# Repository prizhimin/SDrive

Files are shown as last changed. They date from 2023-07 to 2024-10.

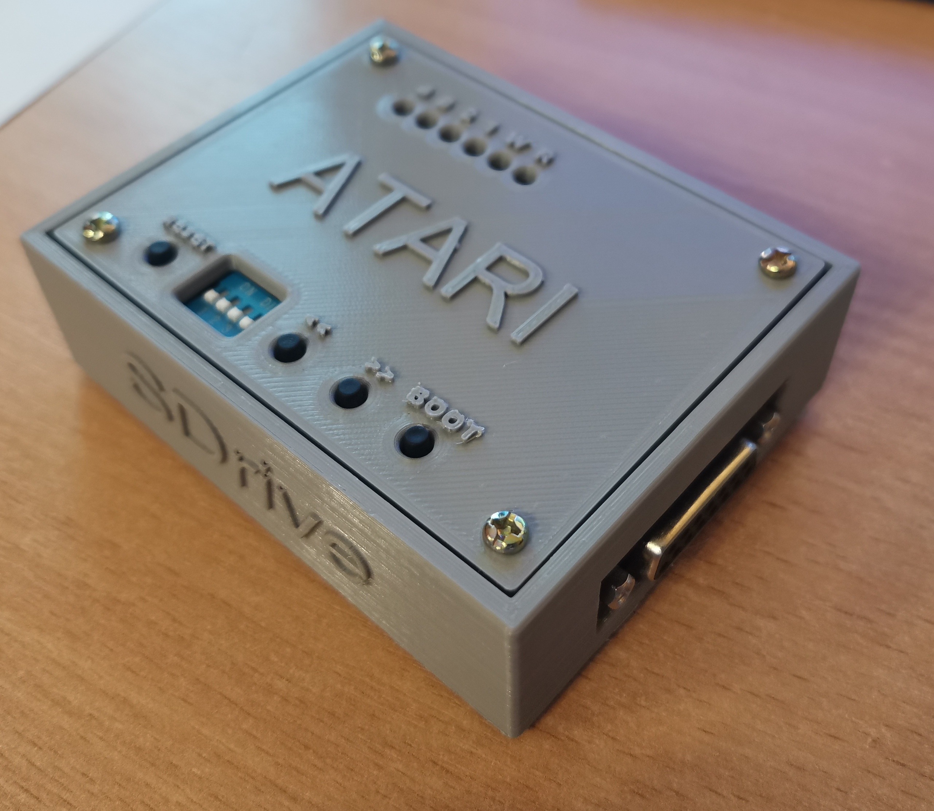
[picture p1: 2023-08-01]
Image 1.jpg

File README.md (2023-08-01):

# SDrive
Информация для создания эмулятора дисковода SDrive для 8-битных компьютеров Atari

Проверена работоспособность на Atari 65XE и Atari 130XL

Версия для микроконтроллера ATmega328P - поддержка карт SDHC и файловой системы FAT32

Оригинальный проект https://github.com/kbr-net/sdrive-ng

------------------------------------------------------------------------

Information for creating an SDrive Drive Emulator for Atari 8-bit computers

Tested performance on Atari 65XE and Atari 130XL

ATmega328P microcontroller version - support for SDHC cards and FAT32 file system

Original project https://github.com/kbr-net/sdrive-ng

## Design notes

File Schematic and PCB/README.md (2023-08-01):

Исходные файлы схемы и печатной платы в формате Diptrace 4

Source of Schematic and PCB in Diptrace 4 format

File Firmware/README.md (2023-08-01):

# SDrive Firmware and Soft

hex и eep - файлы прошивки

sdrive.atr - записать в корень SD-карты

Прошивка:
- во время прошивки все dip-переключатели должны быть внизу (разомкнуты), SD-карта не вставлена, питание 5 вольт подаётся
- прошивать в 2 захода: сначала flash (.hex) и фьюзы, потом eeprom (.eep)

Программатор USBasp с Aliexpress

Программируем при помощи avrdude https://github.com/avrdudes/avrdude

Команда для прошивки фьзов: 
avrdude.exe -p m328p -U lfuse:w:0xfe:m -U hfuse:w:0xd8:m efuse:w:0xfc:m -c usbasp

---------------------------------------------------------------

hex and eep firmware files

sdrive.atr - write to the root of the SD card

Firmware:

- during the firmware, all dip switches must be at the bottom (open), the SD card is not inserted, 5 volts of power is supplied

- to flash in 2 passes: first flash (.hex) and fuses, then eeprom (.eep)

The USBasp programmer with Aliexpress is programmed using avrdude https://github.com/avrdudes/avrdude

The command to burn fuzes: avrdude.exe -p m328p -U lfuse:w:0xfe:m -U hfuse:w:0xd8:m efuse:w:0xfc:m -c usbasp

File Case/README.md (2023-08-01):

# Case for SDrive

Корпус (верх и них) в формате SolidWorks и STL

Top and Bootom in SOLIDWORKS and STL formats

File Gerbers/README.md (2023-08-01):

Готовые герберы печатной платы для заказа на заводе

Ready-made gerbers for ordering PCB at the factory

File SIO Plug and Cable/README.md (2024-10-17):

3D-модель для SIO-коннектора

Взято отсюда https://github.com/schlae/atari-sio

Совместимо с контактами Molex 08-50-0106

Возможно подойдут контакты от разъёма PHU (PHU-6 (DS1072-6F)

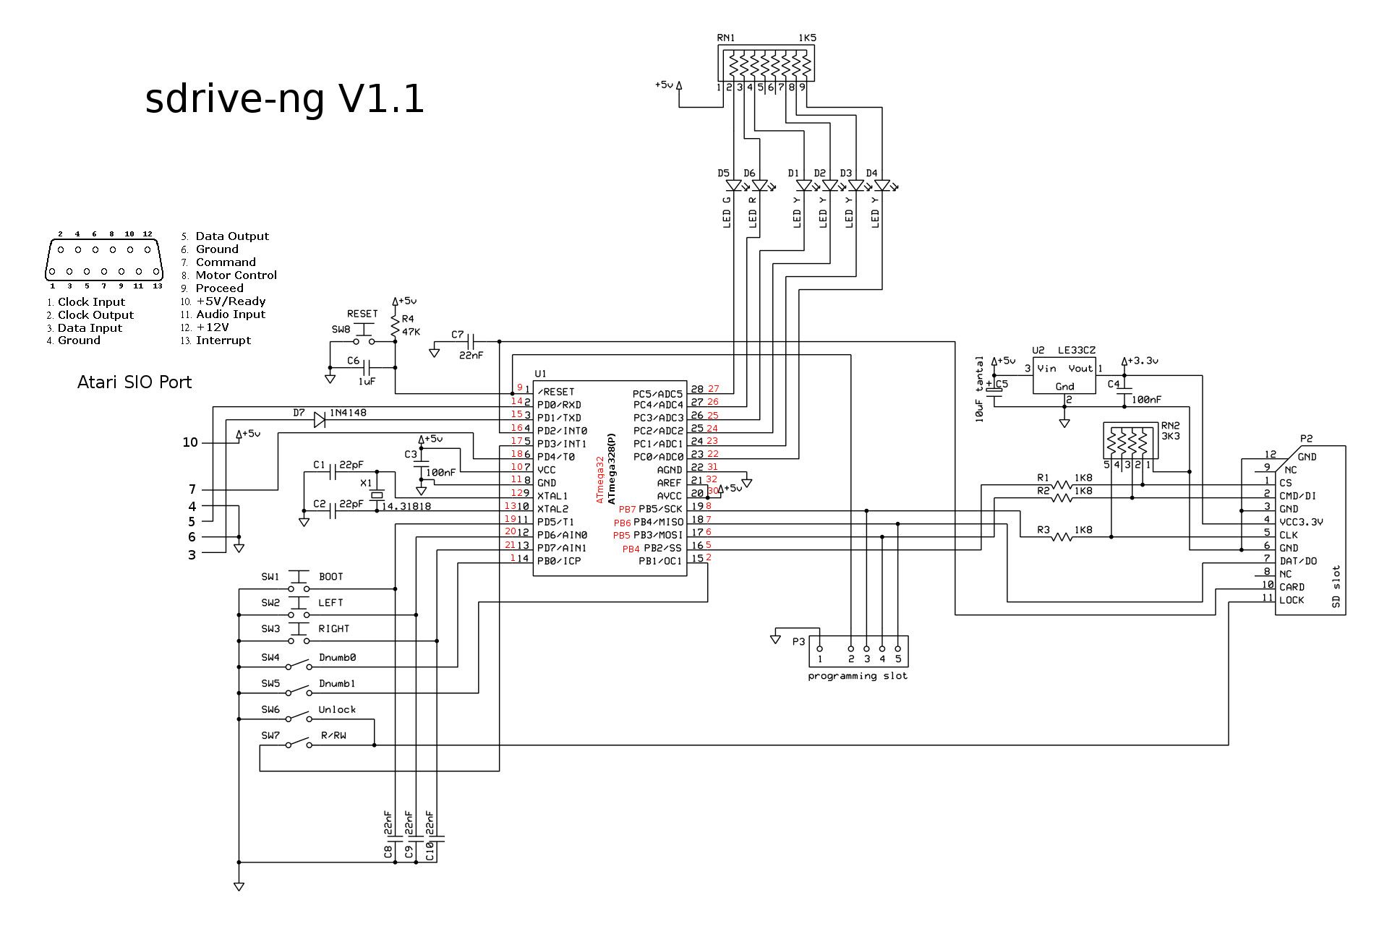
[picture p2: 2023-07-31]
Schematic and PCB/schema-sdrive-ng-v1.1.jpg

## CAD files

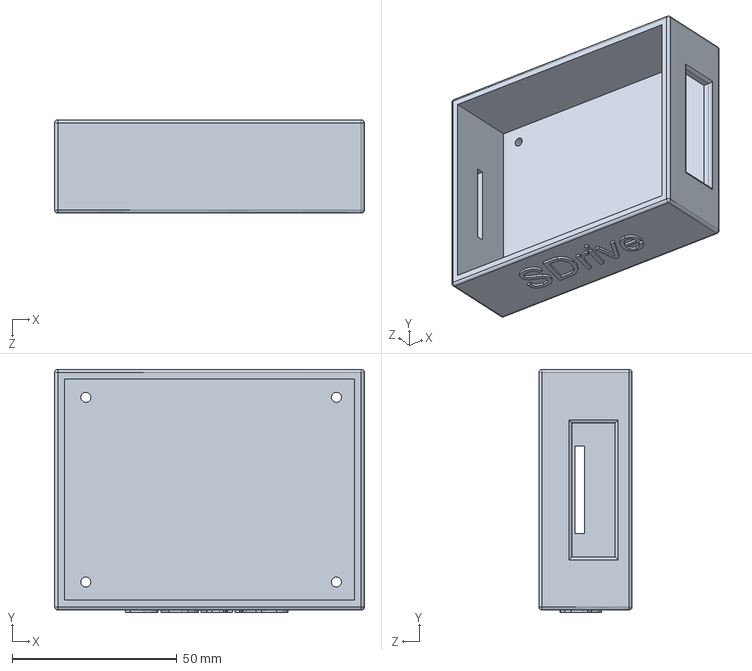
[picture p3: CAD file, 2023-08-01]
Case/Bottom_SDrive.SLDPRT
94.0 x 73.8 x 28.3 mm

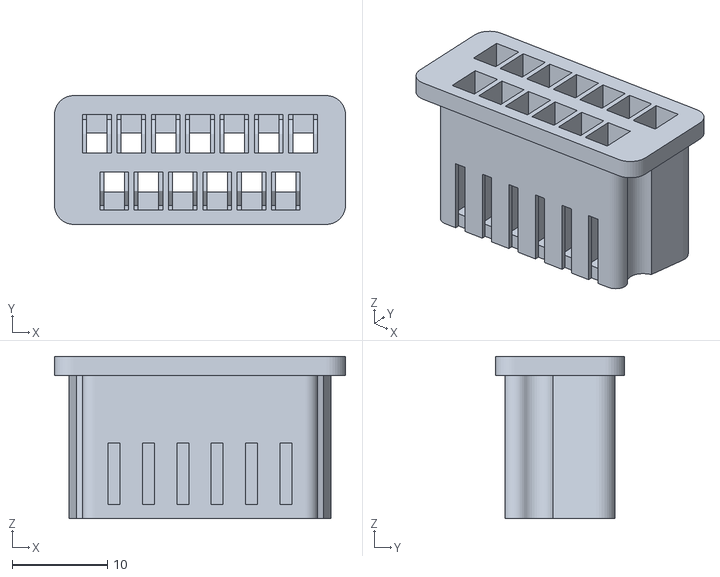
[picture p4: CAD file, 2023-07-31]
SIO Plug and Cable/PlugFront.STL
30.5 x 13.5 x 17.0

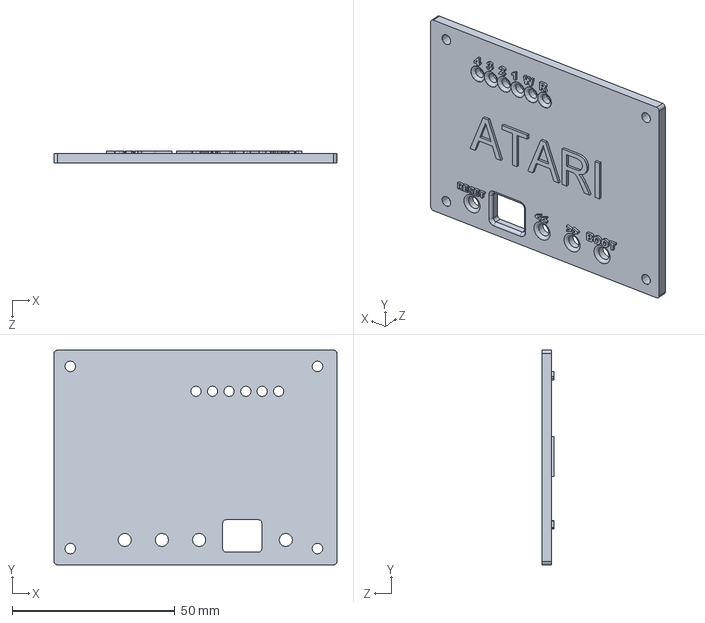
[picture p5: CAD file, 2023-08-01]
Case/Top_SDrive.SLDPRT
87.0 x 66.0 x 3.80 mm

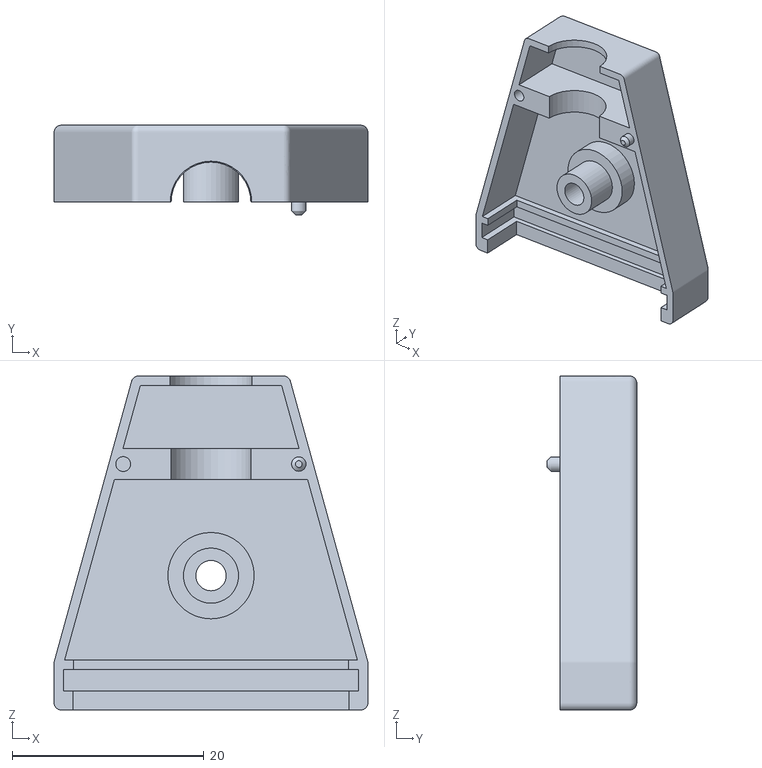
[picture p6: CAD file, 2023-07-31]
SIO Plug and Cable/ShellHalf.STL
32.7 x 9.34 x 34.8

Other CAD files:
Case/Bottom_SDrive.STL
Case/Top_SDrive.STL

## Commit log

2023-07-31 Added gerbers
2023-07-31 Added schematic and 3d-model for SIO Plug
    [PlugFront.STL, ShellHalf.STL]
2023-08-01 Added Schematic and PCB sources in Ditrace format Added Case for SDrive in SOLIDWORKS and STL formats
    [Bottom_SDrive.SLDPRT, Bottom_SDrive.STL, Top_SDrive.SLDPRT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]
2023-08-01 Added Schematic and PCB sources in Diptrace format Added Case for SDrive in SOLIDWORKS and STL formats
